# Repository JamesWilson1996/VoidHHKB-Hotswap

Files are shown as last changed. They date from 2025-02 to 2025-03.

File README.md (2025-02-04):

# VoidHHKB-Hotswap

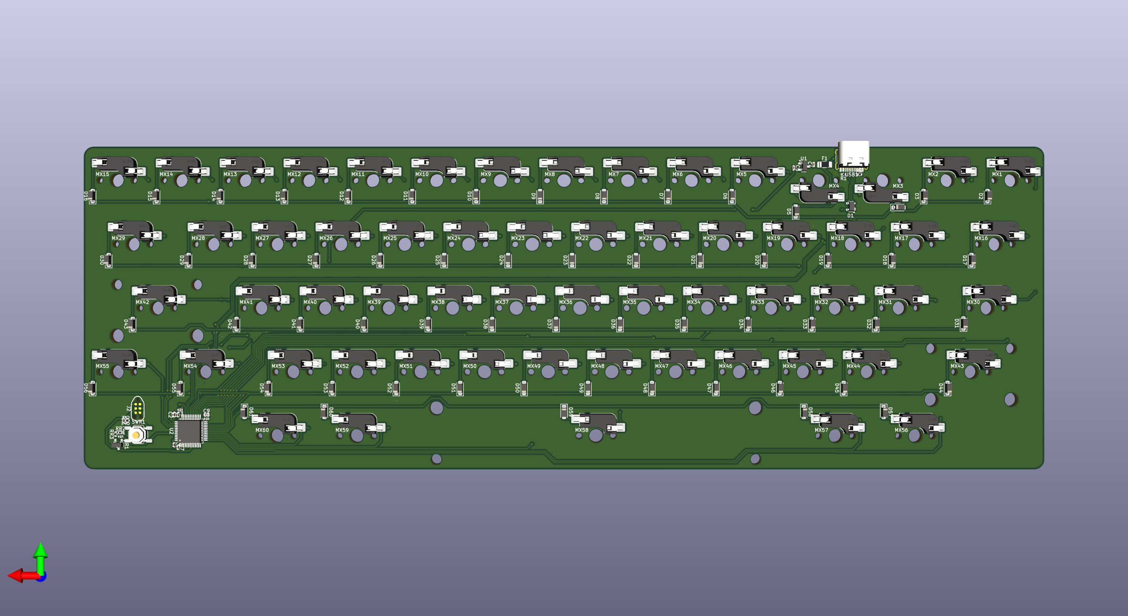
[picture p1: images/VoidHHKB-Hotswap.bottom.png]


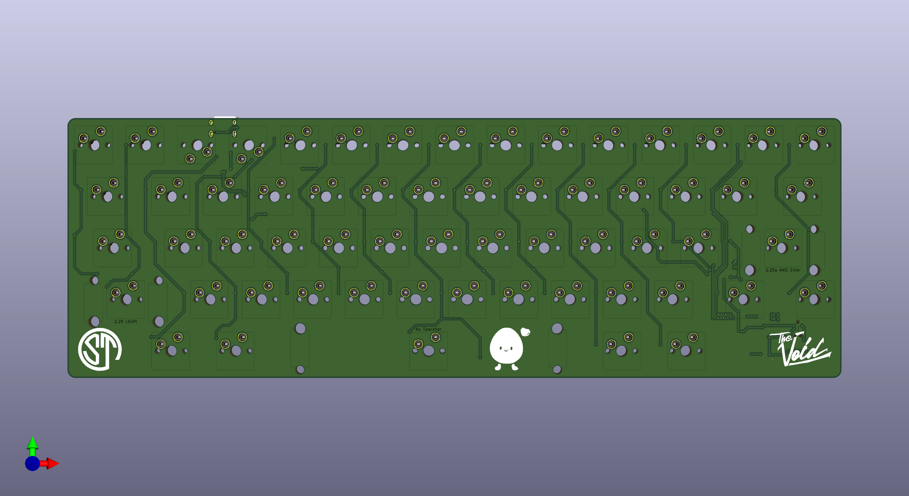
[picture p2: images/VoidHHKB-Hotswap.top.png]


## Ordering from JLCPCB

1) Head to the [JLCPCB order page](https://cart.jlcpcb.com/quote).

2) Upload the `VoidHHKB-Hotswap.zip` file in `production/`.

3) Set the quantity of the PCBs you want made.

4) Set your desired PCB parameters. Here are some suggested parameters: (Everything else can be kept at their default)

- PCB Color: **Purple**
- Surface Finish: **ENIG**
- Remove Order Number: **Yes**   

5) Enable the PCB Assembly option at the bottom, and set the following parameters:

- PCBA Type: **Standard**
- Assembly Side: **Bottom**

6) Press `Confirm` at the bottom or `NEXT` on the right to get to the next page.

7) Click `NEXT` to get to the Bill of Materials tab.

8) Click `Add BOM File` and select the `bom.csv` file in `production/`.

9) Click `Add CPL File` and select the `positions.csv` file in `production/`. Click `Process BOM & CPL` to proceed.

10) You should be presented with a list of all the components and quantities needed. Double check there are no missing components. If there are, you will have to find substitute components for it. Click `NEXT` to proceed.

11) You should be presented with a view of the PCB and its components. You will most likely need to rotate the Hotswap sockets manually. Click `NEXT` to proceed.

12) You should see a breakdown of the price for the PCBs you want to order. Select `Keyboard - HS Code 847330` under `Office Appliance Accessories` for the Product Description.

13) Save to cart, and pay for it!

## Flashing Firmware

1) Install and launch [QMK Toolbox](https://qmk.fm/toolbox)

2) Connect PCB via USB. Hold down reset button to enter bootloader

3) Under 'Local file' open firmware/void_voidhhkb_via.bin. Everything else can be left as default (MCU should be ATmega32U4)

4) Click Flash!

5) Unplug and plug in again to complete set up

## Using VIA

Temp instructions until I get around to merging files into QMK repo...
1) To edit keymap in via open web page and select 'Design' on the top ribbon

2) Click 'Load Draft Definition' and load '/firmware/voidhhkb/via.json'

## Build your own firmware

- Files have been included under 'firmware' if you want to build the bin files yourself.
- This is fairly trivial to do by following the [QMK Tutorial](https://docs.qmk.fm/newbs)

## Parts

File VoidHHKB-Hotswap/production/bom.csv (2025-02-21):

Designator | Footprint | Quantity | Value | LCSC Part #
C1, C8 | 0402 | 2 | 4.7uF | C23733
C2, C3, C7, C9 | 0402 | 4 | 100nF | C1525
C4, C5, C6, CR2 | 0402 | 4 | 1uF | C52923
CR1 | 0402 | 1 | 10uF | C15525
D1 | SOT-143 | 1 | PRTR5V0U2X | C2827688
D10, D11, D12, D13, D14, D15, D16, D17, D18, D19, D2, D20, D21, D22, D23, D24, D25, D26, D27, D28, D29, D3, D30, D31, D32, D33, D34, D35, D36, D37, D38, D39, D4, D40, D41, D42, D43, D44, D45, D46, D47, D48, D49, D5, D50, D51, D52, D53, D54, D55, D56, D57, D58, D59, D6, D60, D61, D7, D8, D9 | D_SOD-123 | 60 | 1N4148W
F1 | 1206 | 1 | 500mA | C69688
MX1, MX10, MX11, MX12, MX13, MX14, MX15, MX17, MX18, MX19, MX2, MX20, MX21, MX22, MX23, MX24, MX25, MX26, MX27, MX28, MX3, MX31, MX32, MX33, MX34, MX35, MX36, MX37, MX38, MX39, MX4, MX40, MX41, MX42, MX43, MX44, MX45, MX46, MX47, MX48, MX49, MX5, MX50, MX51, MX52, MX53, MX55, MX56, MX58, MX6, MX60, MX7, MX8, MX9 | SW_MX_HS_CPG151101S11_1u | 54 | MX_SW_HS
MX16, MX29, MX57, MX59 | SW_MX_HS_CPG151101S11_1.5u | 4 | MX_SW_HS
MX30, MX54 | SW_MX_HS_CPG151101S11_1.75u | 2 | MX_SW_HS
QR1 | SOT-23 | 1 | 2N7002 | C8545
R1, R2 | 0402 | 2 | 5k1 | C25905
RR1 | 0402 | 1 | 33k | C25779
RR2 | 0402 | 1 | 10k | C25744
RR3 | 0402 | 1 | 100k | C25741
SWR1 | SW_SPST_TL3342 | 1 | TS-1187A-B-A-B | C318884
U1 | SOT-23 | 1 | XC6206P332MR | C5446
U2 | LQFP-48_7x7mm_P0.5mm | 1 | STM32F072CBT6 | C81720
USB1 | USB_C_Receptacle_HRO_TYPE-C-31-M-12 | 1 | USB_C_Receptacle_USB2.0_16P | C165948

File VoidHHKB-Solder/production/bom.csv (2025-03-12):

Designator | Footprint | Quantity | Value | LCSC Part #
C1, C8 | 0402 | 2 | 4.7uF | C23733
C2, C3, C7, C9 | 0402 | 4 | 100nF | C1525
C4, C5, C6, CR2 | 0402 | 4 | 1uF | C52923
CR1 | 0402 | 1 | 10uF | C15525
D1 | SOT-143 | 1 | PRTR5V0U2X | C2827688
D10, D11, D12, D13, D14, D15, D16, D17, D18, D19, D2, D20, D21, D22, D23, D24, D25, D26, D27, D28, D29, D3, D30, D31, D32, D33, D34, D35, D36, D37, D38, D39, D4, D40, D41, D42, D43, D44, D45, D46, D47, D48, D49, D5, D50, D51, D52, D53, D54, D55, D56, D57, D58, D59, D6, D60, D61, D62, D63, D7, D8, D9 | D_SOD-123 | 62 | 1N4148W
F1 | 1206 | 1 | 500mA | C69688
MX1 | SW_MX_1u | 1 | Esc
MX10 | SW_MX_1u | 1 | 9
MX11 | SW_MX_1u | 1 | 10
MX12 | SW_MX_1u | 1 | -
MX13 | SW_MX_1u | 1 | =
MX14 | SW_MX_1u | 1 | \
MX15 | SW_MX_1u | 1 | `
MX16 | SW_MX_1u | 1 | Full Backspace
MX17 | SW_MX_1.5u | 1 | Tab
MX18 | SW_MX_1u | 1 | Q
MX19 | SW_MX_1u | 1 | W
MX2 | SW_MX_1u | 1 | 1
MX20 | SW_MX_1u | 1 | E
MX21 | SW_MX_1u | 1 | R
MX22 | SW_MX_1u | 1 | T
MX23 | SW_MX_1u | 1 | Y
MX24 | SW_MX_1u | 1 | U
MX25 | SW_MX_1u | 1 | I
MX26 | SW_MX_1u | 1 | O
MX27 | SW_MX_1u | 1 | P
MX28 | SW_MX_1u | 1 | [
MX29 | SW_MX_1u | 1 | ]
MX3 | SW_MX_1u | 1 | 2
MX30 | SW_MX_1.5u | 1 | Backspace
MX31 | SW_MX_1.75u_STP_1.25 | 1 | Stepped Caps
MX32 | SW_MX_1u | 1 | A
MX33 | SW_MX_1u | 1 | S
MX34 | SW_MX_1u | 1 | D
MX35 | SW_MX_1u | 1 | F
MX36 | SW_MX_1u | 1 | G
MX37 | SW_MX_1u | 1 | H
MX38 | SW_MX_1u | 1 | J
MX39 | SW_MX_1u | 1 | K
MX4 | SW_MX_1u | 1 | 3
MX40 | SW_MX_1u | 1 | L
MX41 | SW_MX_1u | 1 | ;
MX42 | SW_MX_1u | 1 | '
MX43, MX48 | SW_MX_1u | 2 | NUHS
MX44 | SW_MX_1u | 1 | ANSI Enter
MX45 | SW_MX_1.75u | 1 | Caps
MX46 | SW_MX_1u | 1 | ISO Enter
MX47 | SW_MX_1u | 1 | LShift
MX49 | SW_MX_1u | 1 | Z
MX5 | SW_MX_1u | 1 | 4
MX50 | SW_MX_1u | 1 | X
MX51 | SW_MX_1u | 1 | C
MX52 | SW_MX_1u | 1 | V
MX53 | SW_MX_1u | 1 | B
MX54 | SW_MX_1u | 1 | N
MX55 | SW_MX_1u | 1 | M
MX56 | SW_MX_1u | 1 | ,
MX57 | SW_MX_1u | 1 | .
MX58 | SW_MX_1u | 1 | /
MX59 | SW_MX_1.75u | 1 | RShift 1.75u
MX6 | SW_MX_1u | 1 | 5
MX60 | SW_MX_1u | 1 | fn
MX61 | SW_MX_1.25u | 1 | LShift 1.25u
MX62 | SW_MX_1u | 1 | RShift 2.75u
MX63, MX67 | SW_MX_1u | 2 | Alt
MX64, MX66 | SW_MX_1.5u | 2 | Super
MX65 | SW_MX_1u | 1 | Spacebar
MX68 | SW_MX_1u | 1 | Off Center Spacebar
MX7 | SW_MX_1u | 1 | 6
MX8 | SW_MX_1u | 1 | 7
MX9 | SW_MX_1u | 1 | 8
QR1 | SOT-23 | 1 | 2N7002 | C8545
R1, R2 | 0402 | 2 | 5k1 | C25905
RR1 | 0402 | 1 | 33k | C25779
RR2 | 0402 | 1 | 10k | C25744
RR3 | 0402 | 1 | 100k | C25741
S1 | STAB_MX_2u | 1 | 2u Backspace
S3 | STAB_MX_ISO-ROT | 1 | ISO Enter
SWR1 | SW_SPST_TL3342 | 1 | TS-1187A-B-A-B | C318884
U1 | SOT-23 | 1 | XC6206P332MR | C5446
U2 | LQFP-48_7x7mm_P0.5mm | 1 | STM32F072CBT6 | C81720
USB1 | USB_C_Receptacle_HRO_TYPE-C-31-M-12 | 1 | USB_C_Receptacle_USB2.0_16P | C165948

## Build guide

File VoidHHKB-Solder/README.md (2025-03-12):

# VoidHHKB-Solder

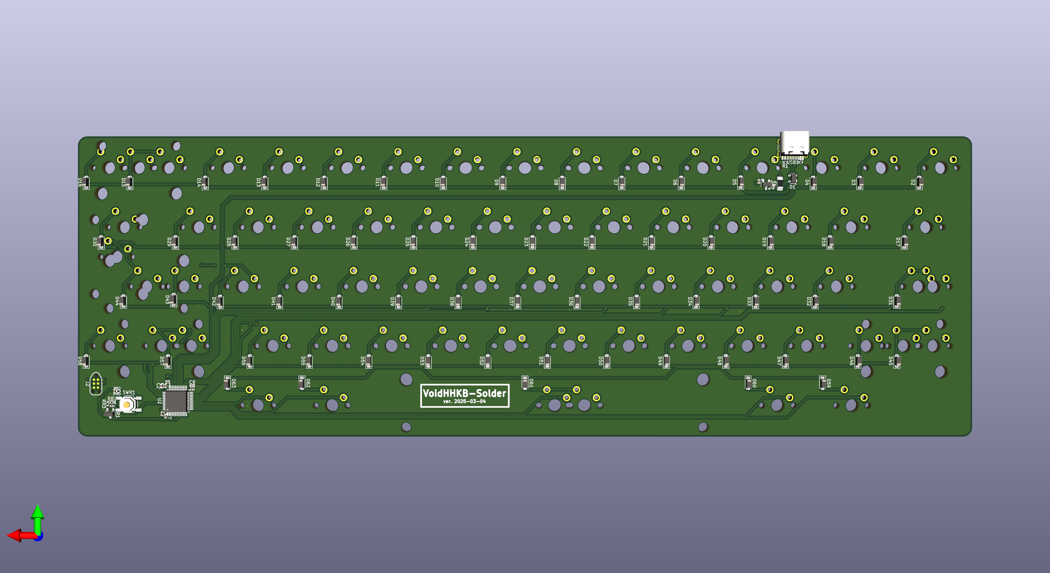
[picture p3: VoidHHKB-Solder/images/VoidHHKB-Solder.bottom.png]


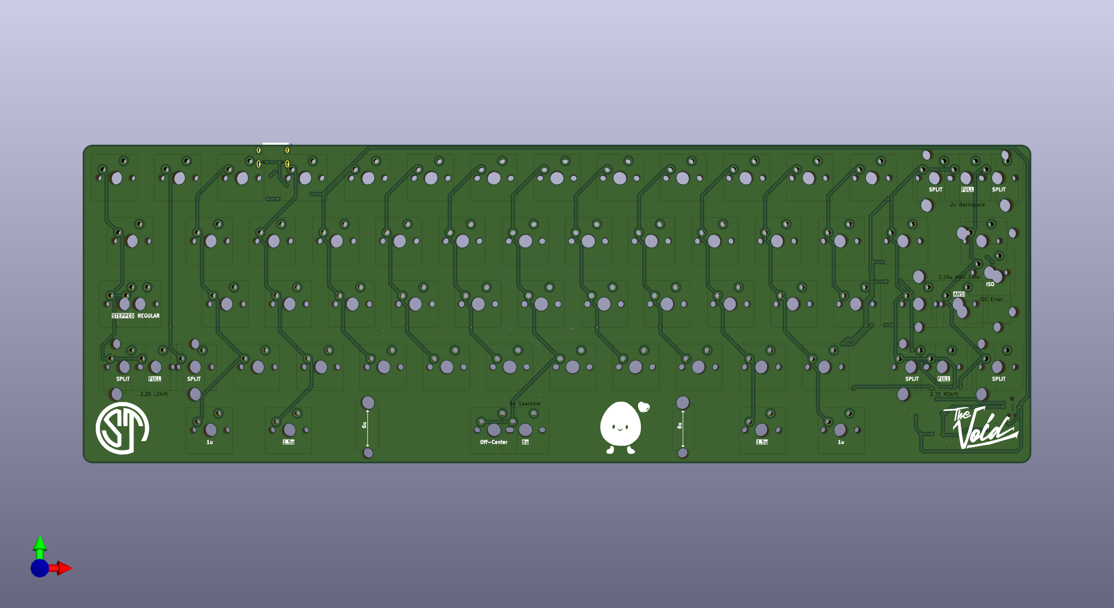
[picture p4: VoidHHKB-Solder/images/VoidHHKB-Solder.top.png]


## Ordering from JLCPCB

1) Head to the [JLCPCB order page](https://cart.jlcpcb.com/quote).

2) Upload the `VoidHHKB-Solder.zip` file in `production/`.

3) Set the quantity of the PCBs you want made.

4) Set your desired PCB parameters. Here are some suggested parameters: (Everything else can be kept at their default)

- PCB Color: **Purple**
- Surface Finish: **ENIG**
- Remove Order Number: **Yes**   

5) Enable the PCB Assembly option at the bottom, and set the following parameters:

- PCBA Type: **Standard**
- Assembly Side: **Bottom**

6) Press `Confirm` at the bottom or `NEXT` on the right to get to the next page.

7) Click `NEXT` to get to the Bill of Materials tab.

8) Click `Add BOM File` and select the `bom.csv` file in `production/`.

9) Click `Add CPL File` and select the `positions.csv` file in `production/`. Click `Process BOM & CPL` to proceed.

10) You should be presented with a list of all the components and quantities needed. Double check there are no missing components. If there are, you will have to find substitute components for it. Click `NEXT` to proceed.

11) You should be presented with a view of the PCB and its components. Click `NEXT` to proceed.

12) You should see a breakdown of the price for the PCBs you want to order. Select `Keyboard - HS Code 847330` under `Office Appliance Accessories` for the Product Description.

13) Save to cart, and pay for it!

## Flashing Firmware

1) Install and launch [QMK Toolbox](https://qmk.fm/toolbox)

2) Connect PCB via USB. Hold down reset button to enter bootloader

3) Under 'Local file' open firmware/void_voidhhkb_via.bin. Everything else can be left as default (MCU should be ATmega32U4)

4) Click Flash!

5) Unplug and plug in again to complete set up

## Using VIA

Temp instructions until I get around to merging files into QMK repo...
1) To edit keymap in via open web page and select 'Design' on the top ribbon

2) Click 'Load Draft Definition' and load '/firmware/voidhhkb/via.json'

## Build your own firmware

- Files have been included under 'firmware' if you want to build the bin files yourself.
- This is fairly trivial to do by following the [QMK Tutorial](https://docs.qmk.fm/newbs)

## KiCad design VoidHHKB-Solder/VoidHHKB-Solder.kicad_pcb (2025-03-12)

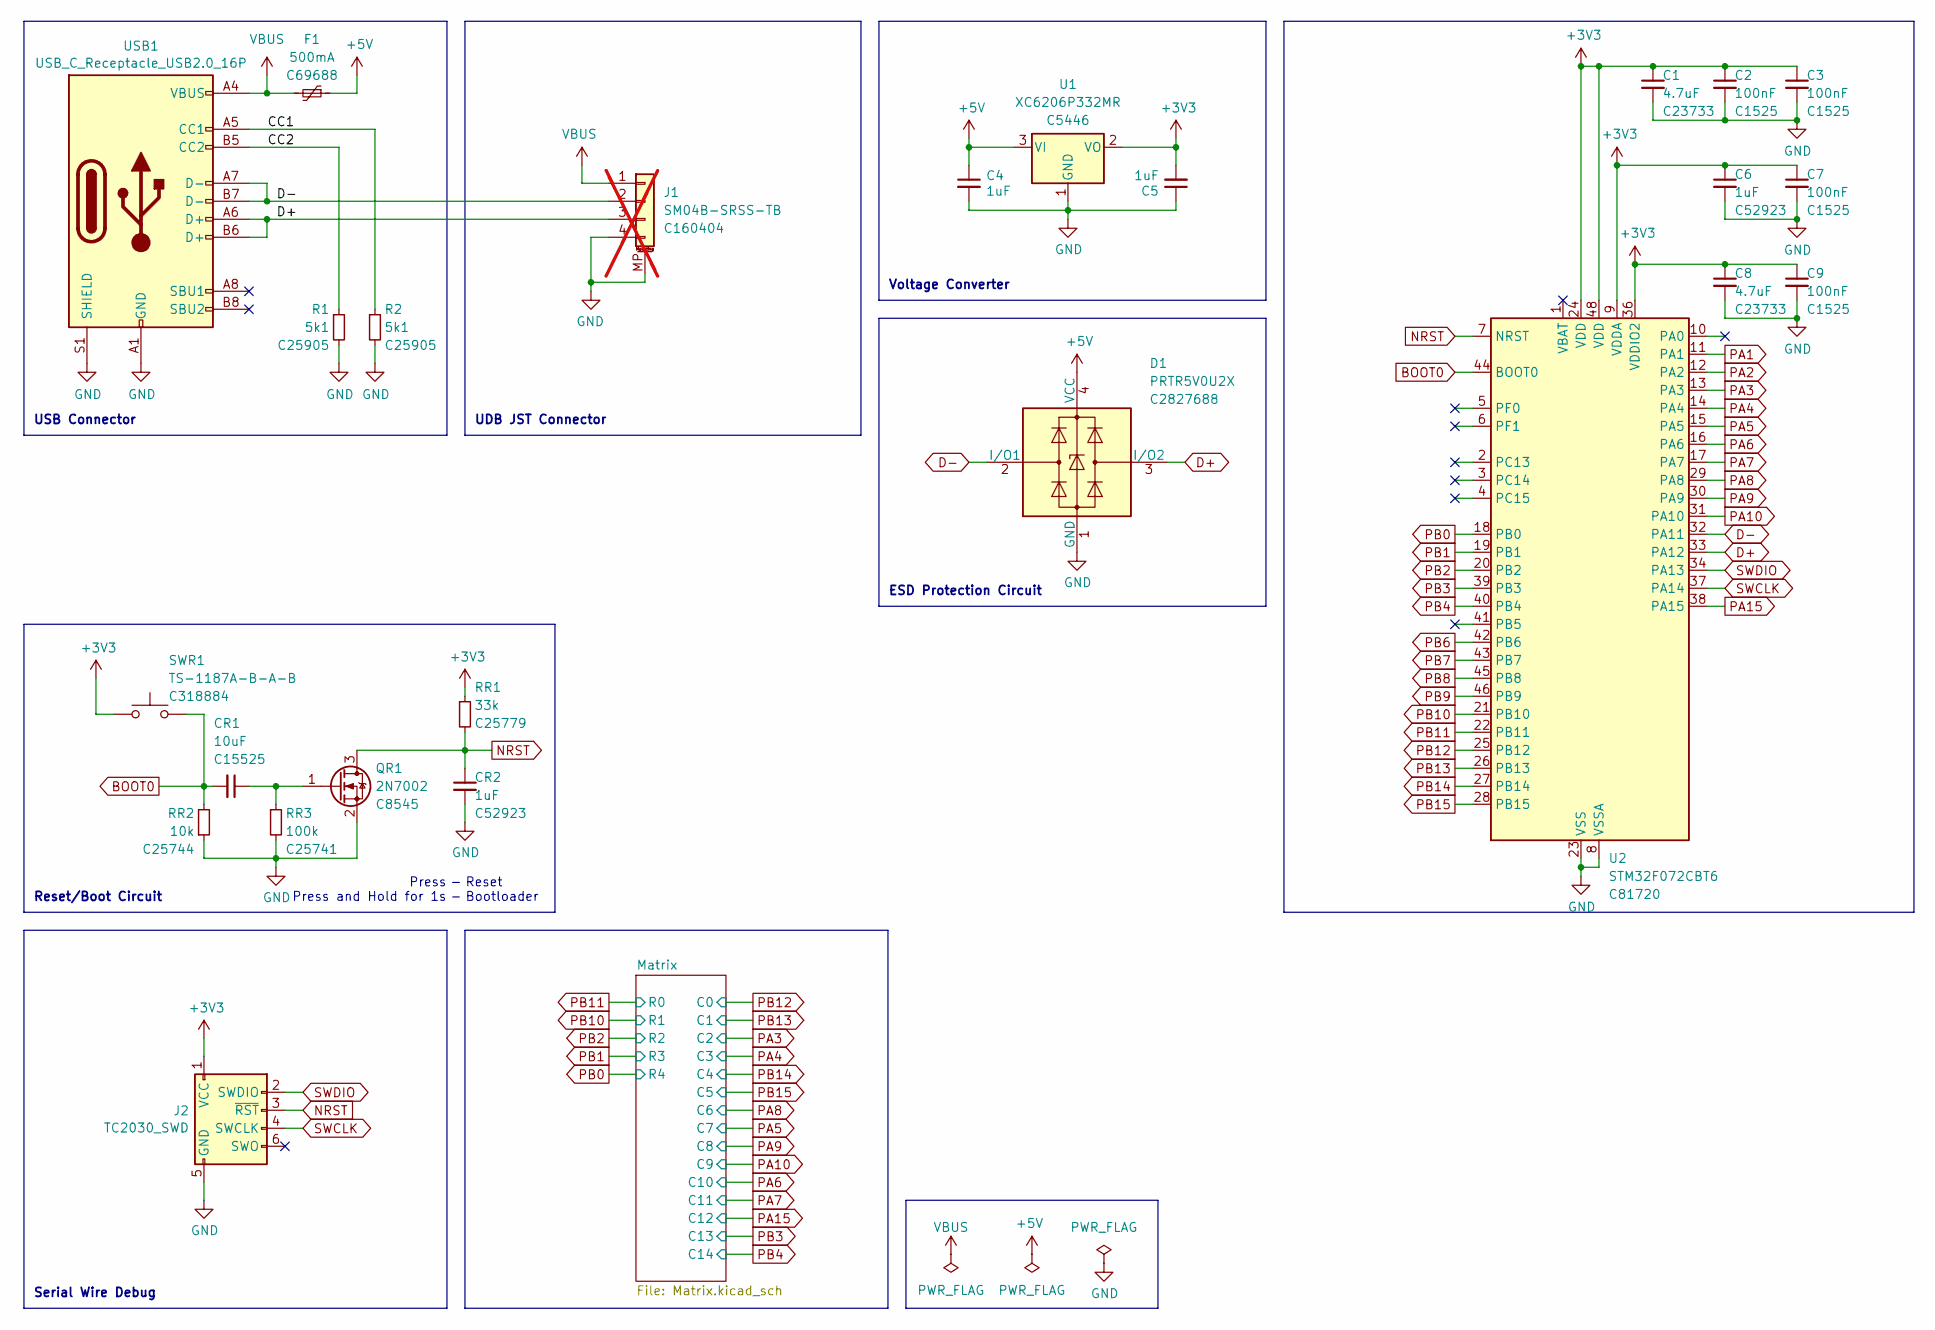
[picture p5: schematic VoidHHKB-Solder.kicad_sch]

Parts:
C1, C8: 4.7uF; C_0402_1005Metric; MPN CL05A475MP5NRNC; LCSC C23733
C2, C3, C7, C9: 100nF; C_0402_1005Metric; MPN CL05B104KO5NNNC; LCSC C1525
C4, C5, C6: 1uF; C_0402_1005Metric; MPN CL05A105KA5NQNC; LCSC C52923
CR1: 10uF; C_0402_1005Metric; MPN CL05A106MQ5NUNC; LCSC C15525
CR2: 1uF; C_0402_1005Metric; MPN CL05A105KA5NQNC; LCSC C52923
D1: PRTR5V0U2X; SOT-143; MPN PRTR5V0U2X; LCSC C2827688
F1: 500mA; Fuse_1206_3216Metric_Pad1.42x1.75mm_HandSolder; MPN nSMD050; LCSC C69688
J1: SM04B-SRSS-TB; JST_SH_SM04B-SRSS-TB_1x04-1MP_P1.00mm_Horizontal; MPN SM04B-SRSS-TB(LF)(SN); LCSC C160404; not fitted
J2: TC2030_SWD; CON_TC2030_outlined
QR1: 2N7002; SOT-23; MPN 2N7002; LCSC C8545
R1, R2: 5k1; R_0402_1005Metric; MPN 0402WGF5101TCE; LCSC C25905
RR1: 33k; R_0402_1005Metric; MPN 0402WGF3302TCE; LCSC C25779
RR2: 10k; R_0402_1005Metric; MPN 0402WGF1002TCE; LCSC C25744
RR3: 100k; R_0402_1005Metric; MPN 0402WGF1003TCE; LCSC C25741
SWR1: TS-1187A-B-A-B; SW_SPST_TL3342; MPN TS-1187A-B-A-B; LCSC C318884
U1: XC6206P332MR; SOT-23; MPN XC6206P332MR-G; LCSC C5446
U2: STM32F072CBT6; LQFP-48_7x7mm_P0.5mm; MPN STM32F072CBT6; LCSC C81720
USB1: USB_C_Receptacle_USB2.0_16P; USB_C_Receptacle_HRO_TYPE-C-31-M-12; MPN TYPE-C-31-M-12; LCSC C165948

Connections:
+3V3: C1.1, C2.1, C3.1, C5.2, C6.1, C7.1, C8.1, C9.1, J2.1 (VCC), RR1.1, SWR1.1, U1.2 (VO), U2.9 (VDDA), U2.24 (VDD), U2.36 (VDDIO2), U2.48 (VDD)
+5V: C4.1, D1.4 (VCC), F1.1, U1.3 (VI)
/CC1: R2.1, USB1.A5 (CC1)
/CC2: R1.1, USB1.B5 (CC2)
BOOT0: CR1.2, RR2.2, SWR1.2, U2.44 (BOOT0)
D+: D1.3 (I/O2), J1.3, U2.33 (PA12), USB1.A6 (D+), USB1.B6 (D+)
D-: D1.2 (I/O1), J1.2, U2.32 (PA11), USB1.A7 (D-), USB1.B7 (D-)
GND: C1.2, C2.2, C3.2, C4.2, C5.1, C6.2, C7.2, C8.2, C9.2, CR2.2, D1.1 (GND), J1.4, J1.MP (MountPin), J2.5 (GND), QR1.2 (S), R1.2, R2.2, RR2.1, RR3.2, U1.1 (GND), U2.8 (VSSA), U2.23 (VSS), U2.35 (VSS), U2.47 (VSS), USB1.A1 (GND), USB1.A12 (GND), USB1.B1 (GND), USB1.B12 (GND), USB1.S1 (SHIELD)
NRST: CR2.1, J2.3 (~RST), QR1.3 (D), RR1.2, U2.7 (NRST)
unnamed: CR1.1, QR1.1 (G), RR3.1
PA1: U2.11 (PA1)
PA2: U2.12 (PA2)
PA3: U2.13 (PA3); also elsewhere on the board
PA4: U2.14 (PA4); also elsewhere on the board
PA5: U2.15 (PA5); also elsewhere on the board
PA6: U2.16 (PA6); also elsewhere on the board
PA7: U2.17 (PA7); also elsewhere on the board
PA8: U2.29 (PA8); also elsewhere on the board
PA9: U2.30 (PA9); also elsewhere on the board
PA10: U2.31 (PA10); also elsewhere on the board
PA15: U2.38 (PA15); also elsewhere on the board
PB0: U2.18 (PB0); also elsewhere on the board
PB1: U2.19 (PB1); also elsewhere on the board
PB2: U2.20 (PB2); also elsewhere on the board
PB3: U2.39 (PB3); also elsewhere on the board
PB4: U2.40 (PB4); also elsewhere on the board
PB6: U2.42 (PB6)
PB7: U2.43 (PB7)
PB8: U2.45 (PB8)
PB9: U2.46 (PB9)
PB10: U2.21 (PB10); also elsewhere on the board
PB11: U2.22 (PB11); also elsewhere on the board
PB12: U2.25 (PB12); also elsewhere on the board
PB13: U2.26 (PB13); also elsewhere on the board
PB14: U2.27 (PB14); also elsewhere on the board
PB15: U2.28 (PB15); also elsewhere on the board
SWCLK: J2.4 (SWCLK), U2.37 (PA14)
SWDIO: J2.2 (SWDIO), U2.34 (PA13)
VBUS: F1.2, J1.1, USB1.A4 (VBUS), USB1.A9 (VBUS), USB1.B4 (VBUS), USB1.B9 (VBUS)

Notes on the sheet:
Reset Bootloader
- -
ESD Protection Circuit
Voltage Converter
Serial Wire Debug
Press Press and Hold for 1s
Reset/Boot Circuit
USB Connector
UDB JST Connector

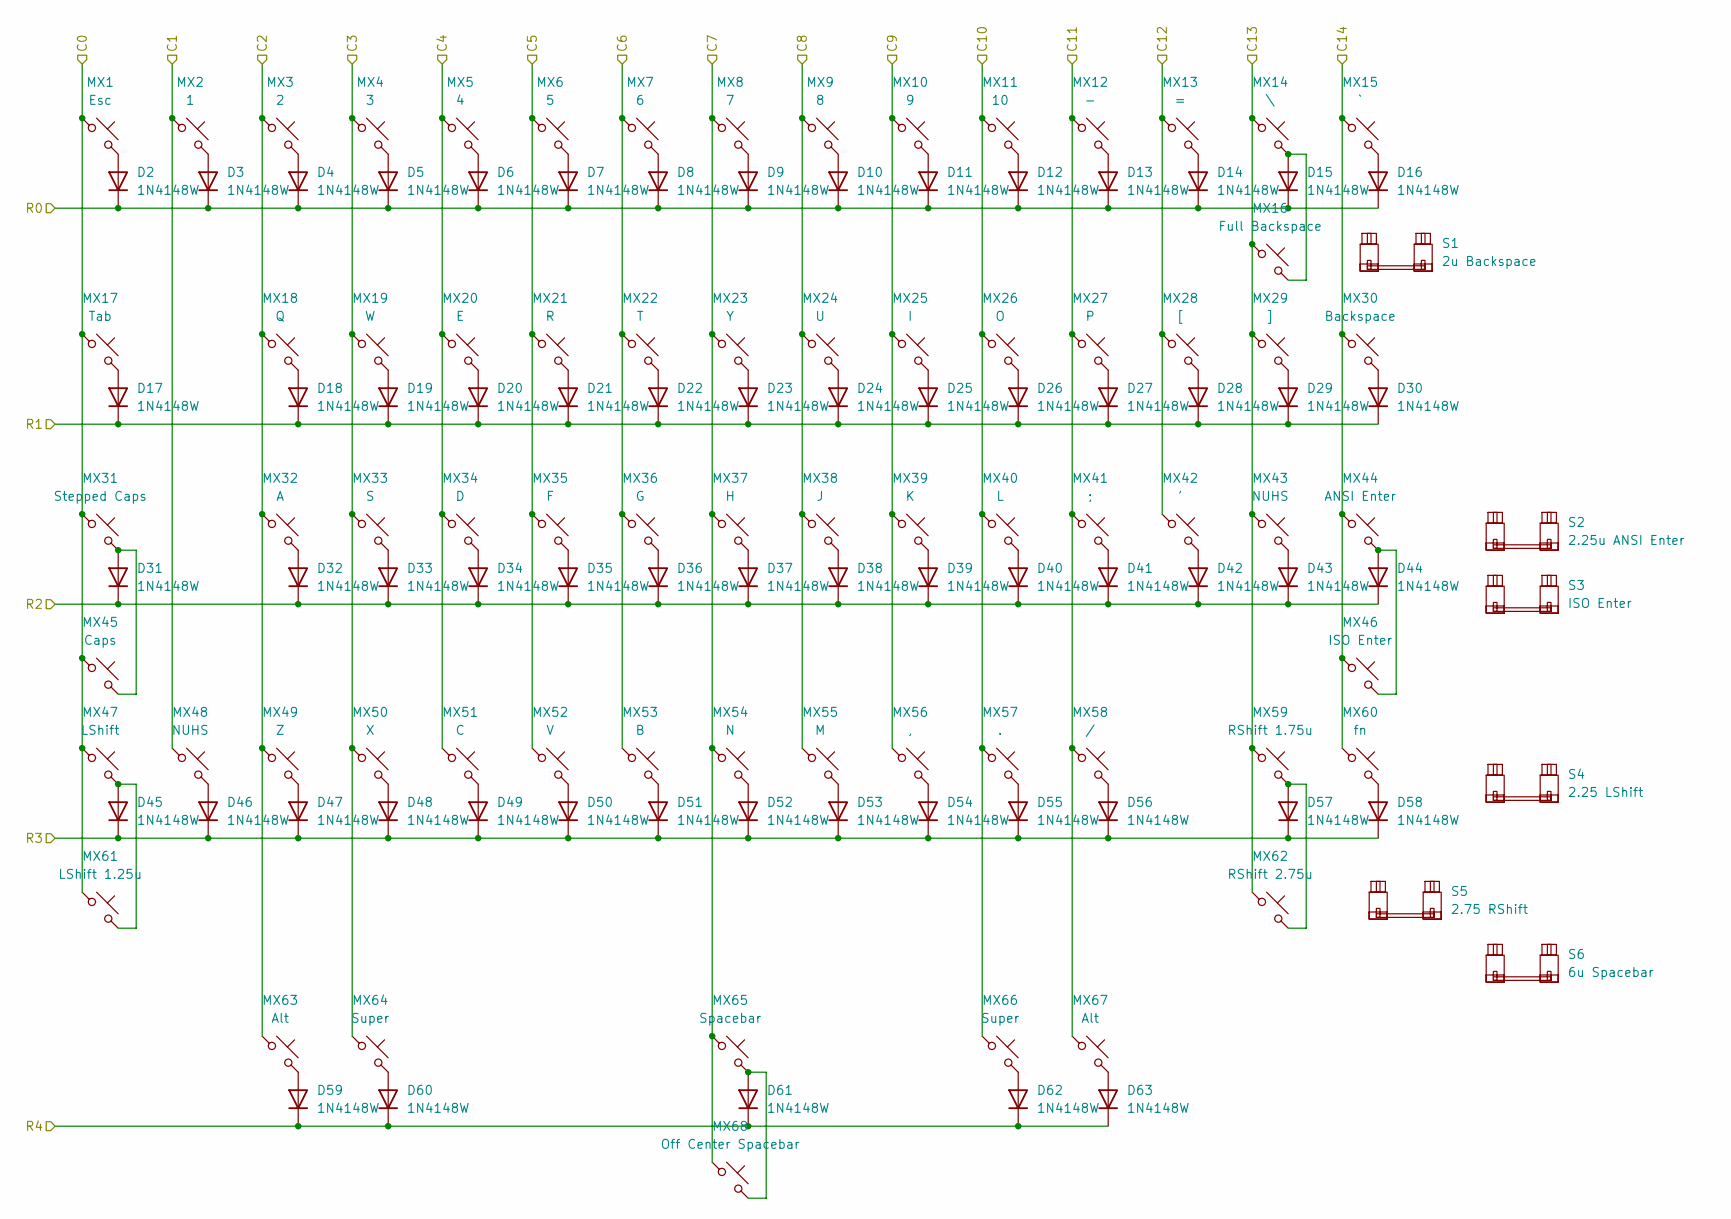
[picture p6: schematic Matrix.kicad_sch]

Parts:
D2, D3, D4, D5, D6, D7, D8, D9, D10, D11, D12, D13, D14, D15, D16, D17, D18, D19, D20, D21, D22, D23, D24, D25, D26, D27, D28, D29, D30, D31, D32, D33, D34, D35, D36, D37, D38, D39, D40, D41, D42, D43, D44, D45, D46, D47, D48, D49, D50, D51, D52, D53, D54, D55, D56, D57, D58, D59, D60, D61, D62, D63: 1N4148W; D_SOD-123
MX1: Esc; SW_MX_1u
MX2: 1; SW_MX_1u
MX3: 2; SW_MX_1u
MX4: 3; SW_MX_1u
MX5: 4; SW_MX_1u
MX6: 5; SW_MX_1u
MX7: 6; SW_MX_1u
MX8: 7; SW_MX_1u
MX9: 8; SW_MX_1u
MX10: 9; SW_MX_1u
MX11: 10; SW_MX_1u
MX12: -; SW_MX_1u
MX13: =; SW_MX_1u
MX14: \; SW_MX_1u
MX15: `; SW_MX_1u
MX16: Full Backspace; SW_MX_1u
MX17: Tab; SW_MX_1.5u
MX18: Q; SW_MX_1u
MX19: W; SW_MX_1u
MX20: E; SW_MX_1u
MX21: R; SW_MX_1u
MX22: T; SW_MX_1u
MX23: Y; SW_MX_1u
MX24: U; SW_MX_1u
MX25: I; SW_MX_1u
MX26: O; SW_MX_1u
MX27: P; SW_MX_1u
MX28: [; SW_MX_1u
MX29: ]; SW_MX_1u
MX30: Backspace; SW_MX_1.5u
MX31: Stepped Caps; SW_MX_1.75u_STP_1.25
MX32: A; SW_MX_1u
MX33: S; SW_MX_1u
MX34: D; SW_MX_1u
MX35: F; SW_MX_1u
MX36: G; SW_MX_1u
MX37: H; SW_MX_1u
MX38: J; SW_MX_1u
MX39: K; SW_MX_1u
MX40: L; SW_MX_1u
MX41: ;; SW_MX_1u
MX42: '; SW_MX_1u
MX43, MX48: NUHS; SW_MX_1u
MX44: ANSI Enter; SW_MX_1u
MX45: Caps; SW_MX_1.75u
MX46: ISO Enter; SW_MX_1u
MX47: LShift; SW_MX_1u
MX49: Z; SW_MX_1u
MX50: X; SW_MX_1u
MX51: C; SW_MX_1u
MX52: V; SW_MX_1u
MX53: B; SW_MX_1u
MX54: N; SW_MX_1u
MX55: M; SW_MX_1u
MX56: ,; SW_MX_1u
MX57: .; SW_MX_1u
MX58: /; SW_MX_1u
MX59: RShift 1.75u; SW_MX_1.75u
MX60: fn; SW_MX_1u
MX61: LShift 1.25u; SW_MX_1.25u
MX62: RShift 2.75u; SW_MX_1u
MX63, MX67: Alt; SW_MX_1u
MX64, MX66: Super; SW_MX_1.5u
MX65: Spacebar; SW_MX_1u
MX68: Off Center Spacebar; SW_MX_1u
S1: 2u Backspace; STAB_MX_2u
S2: 2.25u ANSI Enter; STAB_MX_2.25u
S3: ISO Enter; STAB_MX_ISO-ROT
S4: 2.25 LShift; STAB_MX_2.25u
S5: 2.75 RShift; STAB_MX_2.75u
S6: 6u Spacebar; STAB_MX_6u_New

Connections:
unnamed: D2.2 (A), MX1.2
unnamed: D3.2 (A), MX2.2
unnamed: D4.2 (A), MX3.2
unnamed: D5.2 (A), MX4.2
unnamed: D6.2 (A), MX5.2
unnamed: D7.2 (A), MX6.2
unnamed: D8.2 (A), MX7.2
unnamed: D9.2 (A), MX8.2
unnamed: D10.2 (A), MX9.2
unnamed: D11.2 (A), MX10.2
unnamed: D12.2 (A), MX11.2
unnamed: D13.2 (A), MX12.2
unnamed: D14.2 (A), MX13.2
unnamed: D15.2 (A), MX14.2, MX16.2
unnamed: D16.2 (A), MX15.2
unnamed: D17.2 (A), MX17.2
unnamed: D18.2 (A), MX18.2
unnamed: D19.2 (A), MX19.2
unnamed: D20.2 (A), MX20.2
unnamed: D21.2 (A), MX21.2
unnamed: D22.2 (A), MX22.2
unnamed: D23.2 (A), MX23.2
unnamed: D24.2 (A), MX24.2
unnamed: D25.2 (A), MX25.2
unnamed: D26.2 (A), MX26.2
unnamed: D27.2 (A), MX27.2
unnamed: D28.2 (A), MX28.2
unnamed: D29.2 (A), MX29.2
unnamed: D30.2 (A), MX30.2
unnamed: D31.2 (A), MX31.2, MX45.2
unnamed: D32.2 (A), MX32.2
unnamed: D33.2 (A), MX33.2
unnamed: D34.2 (A), MX34.2
unnamed: D35.2 (A), MX35.2
unnamed: D36.2 (A), MX36.2
unnamed: D37.2 (A), MX37.2
unnamed: D38.2 (A), MX38.2
unnamed: D39.2 (A), MX39.2
unnamed: D40.2 (A), MX40.2
unnamed: D41.2 (A), MX41.2
unnamed: D42.2 (A), MX42.2
unnamed: D43.2 (A), MX43.2
unnamed: D44.2 (A), MX44.2, MX46.2
unnamed: D45.2 (A), MX47.2, MX61.2
unnamed: D46.2 (A), MX48.2
unnamed: D47.2 (A), MX49.2
unnamed: D48.2 (A), MX50.2
unnamed: D49.2 (A), MX51.2
unnamed: D50.2 (A), MX52.2
unnamed: D51.2 (A), MX53.2
unnamed: D52.2 (A), MX54.2
unnamed: D53.2 (A), MX55.2
unnamed: D54.2 (A), MX56.2
unnamed: D55.2 (A), MX57.2
unnamed: D56.2 (A), MX58.2
unnamed: D57.2 (A), MX59.2, MX62.2
unnamed: D58.2 (A), MX60.2
unnamed: D59.2 (A), MX63.2
unnamed: D60.2 (A), MX64.2
unnamed: D61.2 (A), MX65.2, MX68.2
unnamed: D62.2 (A), MX66.2
unnamed: D63.2 (A), MX67.2
PA3: MX3.1, MX18.1, MX32.1, MX49.1, MX63.1; also elsewhere on the board
PA4: MX4.1, MX19.1, MX33.1, MX50.1, MX64.1; also elsewhere on the board
PA5: MX8.1, MX23.1, MX37.1, MX54.1, MX65.1, MX68.1; also elsewhere on the board
PA6: MX11.1, MX26.1, MX40.1, MX57.1, MX66.1; also elsewhere on the board
PA7: MX12.1, MX27.1, MX41.1, MX58.1, MX67.1; also elsewhere on the board
PA8: MX7.1, MX22.1, MX36.1, MX53.1; also elsewhere on the board
PA9: MX9.1, MX24.1, MX38.1, MX55.1; also elsewhere on the board
PA10: MX10.1, MX25.1, MX39.1, MX56.1; also elsewhere on the board
PA15: MX13.1, MX28.1, MX42.1; also elsewhere on the board
PB0: D59.1 (K), D60.1 (K), D61.1 (K), D62.1 (K), D63.1 (K); also elsewhere on the board
PB1: D45.1 (K), D46.1 (K), D47.1 (K), D48.1 (K), D49.1 (K), D50.1 (K), D51.1 (K), D52.1 (K), D53.1 (K), D54.1 (K), D55.1 (K), D56.1 (K), D57.1 (K), D58.1 (K); also elsewhere on the board
PB2: D31.1 (K), D32.1 (K), D33.1 (K), D34.1 (K), D35.1 (K), D36.1 (K), D37.1 (K), D38.1 (K), D39.1 (K), D40.1 (K), D41.1 (K), D42.1 (K), D43.1 (K), D44.1 (K); also elsewhere on the board
PB3: MX14.1, MX16.1, MX29.1, MX43.1, MX59.1, MX62.1; also elsewhere on the board
PB4: MX15.1, MX30.1, MX44.1, MX46.1, MX60.1; also elsewhere on the board
PB10: D17.1 (K), D18.1 (K), D19.1 (K), D20.1 (K), D21.1 (K), D22.1 (K), D23.1 (K), D24.1 (K), D25.1 (K), D26.1 (K), D27.1 (K), D28.1 (K), D29.1 (K), D30.1 (K); also elsewhere on the board
PB11: D2.1 (K), D3.1 (K), D4.1 (K), D5.1 (K), D6.1 (K), D7.1 (K), D8.1 (K), D9.1 (K), D10.1 (K), D11.1 (K), D12.1 (K), D13.1 (K), D14.1 (K), D15.1 (K), D16.1 (K); also elsewhere on the board
PB12: MX1.1, MX17.1, MX31.1, MX45.1, MX47.1, MX61.1; also elsewhere on the board
PB13: MX2.1, MX48.1; also elsewhere on the board
PB14: MX5.1, MX20.1, MX34.1, MX51.1; also elsewhere on the board
PB15: MX6.1, MX21.1, MX35.1, MX52.1; also elsewhere on the board

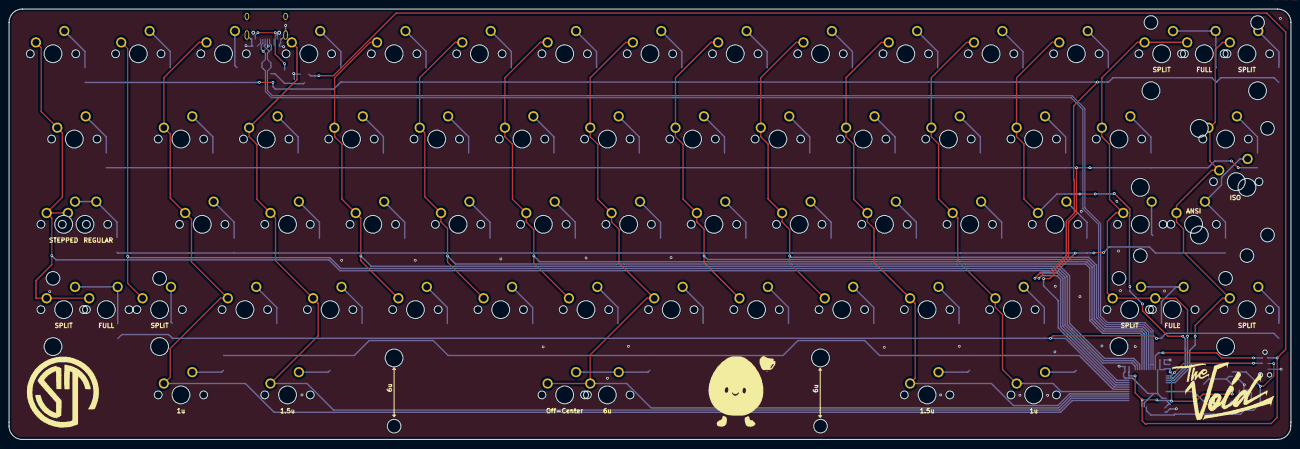
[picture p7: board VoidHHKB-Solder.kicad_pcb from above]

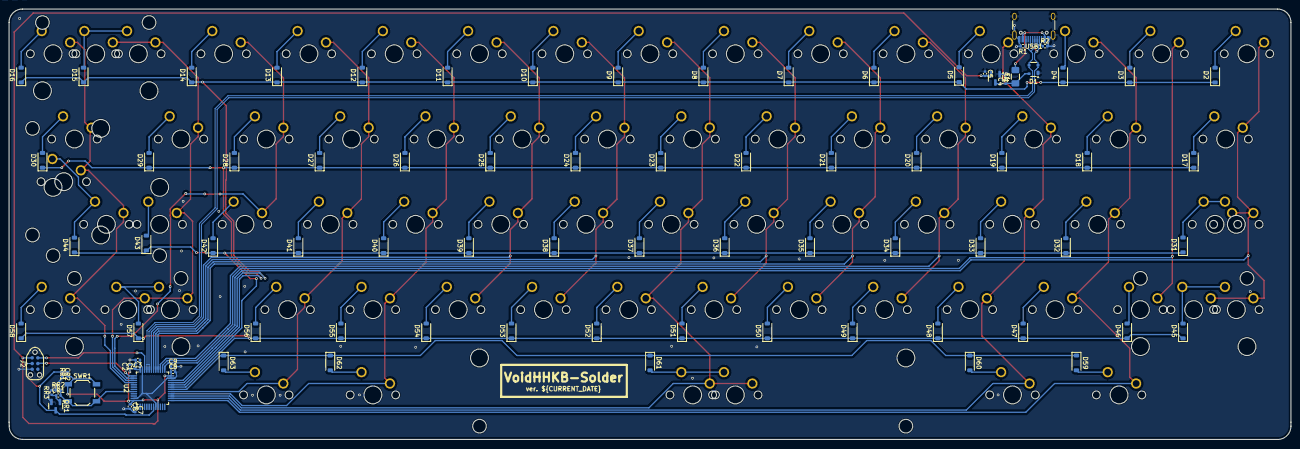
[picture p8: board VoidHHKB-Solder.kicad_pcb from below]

Board: 2 copper layers, 286.4 x 96.1 mm, 160 parts (86 on the bottom side), 95 nets.

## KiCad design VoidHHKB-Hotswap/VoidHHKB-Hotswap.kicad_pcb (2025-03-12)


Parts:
C1, C8: 4.7uF; C_0402_1005Metric; MPN CL05A475MP5NRNC; LCSC C23733
C2, C3, C7, C9: 100nF; C_0402_1005Metric; MPN CL05B104KO5NNNC; LCSC C1525
C4, C5, C6: 1uF; C_0402_1005Metric; MPN CL05A105KA5NQNC; LCSC C52923
CR1: 10uF; C_0402_1005Metric; MPN CL05A106MQ5NUNC; LCSC C15525
CR2: 1uF; C_0402_1005Metric; MPN CL05A105KA5NQNC; LCSC C52923
D1: PRTR5V0U2X; SOT-143; MPN PRTR5V0U2X; LCSC C2827688
F1: 500mA; Fuse_1206_3216Metric_Pad1.42x1.75mm_HandSolder; MPN nSMD050; LCSC C69688
J1: SM04B-SRSS-TB; JST_SH_SM04B-SRSS-TB_1x04-1MP_P1.00mm_Horizontal; MPN SM04B-SRSS-TB(LF)(SN); LCSC C160404; not fitted
J2: TC2030_SWD; CON_TC2030_outlined
QR1: 2N7002; SOT-23; MPN 2N7002; LCSC C8545
R1, R2: 5k1; R_0402_1005Metric; MPN 0402WGF5101TCE; LCSC C25905
RR1: 33k; R_0402_1005Metric; MPN 0402WGF3302TCE; LCSC C25779
RR2: 10k; R_0402_1005Metric; MPN 0402WGF1002TCE; LCSC C25744
RR3: 100k; R_0402_1005Metric; MPN 0402WGF1003TCE; LCSC C25741
SWR1: TS-1187A-B-A-B; SW_SPST_TL3342; MPN TS-1187A-B-A-B; LCSC C318884
U1: XC6206P332MR; SOT-23; MPN XC6206P332MR-G; LCSC C5446
U2: STM32F072CBT6; LQFP-48_7x7mm_P0.5mm; MPN STM32F072CBT6; LCSC C81720
USB1: USB_C_Receptacle_USB2.0_16P; USB_C_Receptacle_HRO_TYPE-C-31-M-12; MPN TYPE-C-31-M-12; LCSC C165948

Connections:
+3V3: C1.1, C2.1, C3.1, C5.2, C6.1, C7.1, C8.1, C9.1, J2.1 (VCC), RR1.1, SWR1.1, U1.2 (VO), U2.9 (VDDA), U2.24 (VDD), U2.36 (VDDIO2), U2.48 (VDD)
+5V: C4.1, D1.4 (VCC), F1.1, U1.3 (VI)
/CC1: R2.1, USB1.A5 (CC1)
/CC2: R1.1, USB1.B5 (CC2)
BOOT0: CR1.2, RR2.2, SWR1.2, U2.44 (BOOT0)
D+: D1.3 (I/O2), J1.3, U2.33 (PA12), USB1.A6 (D+), USB1.B6 (D+)
D-: D1.2 (I/O1), J1.2, U2.32 (PA11), USB1.A7 (D-), USB1.B7 (D-)
GND: C1.2, C2.2, C3.2, C4.2, C5.1, C6.2, C7.2, C8.2, C9.2, CR2.2, D1.1 (GND), J1.4, J1.MP (MountPin), J2.5 (GND), QR1.2 (S), R1.2, R2.2, RR2.1, RR3.2, U1.1 (GND), U2.8 (VSSA), U2.23 (VSS), U2.35 (VSS), U2.47 (VSS), USB1.A1 (GND), USB1.A12 (GND), USB1.B1 (GND), USB1.B12 (GND), USB1.S1 (SHIELD)
NRST: CR2.1, J2.3 (~RST), QR1.3 (D), RR1.2, U2.7 (NRST)
unnamed: CR1.1, QR1.1 (G), RR3.1
PA1: U2.11 (PA1)
PA2: U2.12 (PA2)
PA3: U2.13 (PA3); also elsewhere on the board
PA4: U2.14 (PA4); also elsewhere on the board
PA5: U2.15 (PA5); also elsewhere on the board
PA6: U2.16 (PA6); also elsewhere on the board
PA7: U2.17 (PA7); also elsewhere on the board
PA8: U2.29 (PA8); also elsewhere on the board
PA9: U2.30 (PA9); also elsewhere on the board
PA10: U2.31 (PA10); also elsewhere on the board
PA15: U2.38 (PA15); also elsewhere on the board
PB0: U2.18 (PB0); also elsewhere on the board
PB1: U2.19 (PB1); also elsewhere on the board
PB2: U2.20 (PB2); also elsewhere on the board
PB3: U2.39 (PB3); also elsewhere on the board
PB4: U2.40 (PB4); also elsewhere on the board
PB6: U2.42 (PB6)
PB7: U2.43 (PB7)
PB8: U2.45 (PB8)
PB9: U2.46 (PB9)
PB10: U2.21 (PB10); also elsewhere on the board
PB11: U2.22 (PB11); also elsewhere on the board
PB12: U2.25 (PB12); also elsewhere on the board
PB13: U2.26 (PB13); also elsewhere on the board
PB14: U2.27 (PB14); also elsewhere on the board
PB15: U2.28 (PB15); also elsewhere on the board
SWCLK: J2.4 (SWCLK), U2.37 (PA14)
SWDIO: J2.2 (SWDIO), U2.34 (PA13)
VBUS: F1.2, J1.1, USB1.A4 (VBUS), USB1.A9 (VBUS), USB1.B4 (VBUS), USB1.B9 (VBUS)

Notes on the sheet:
Reset Bootloader
- -
ESD Protection Circuit
Voltage Converter
Serial Wire Debug
Press Press and Hold for 1s
Reset/Boot Circuit
USB Connector
UDB JST Connector

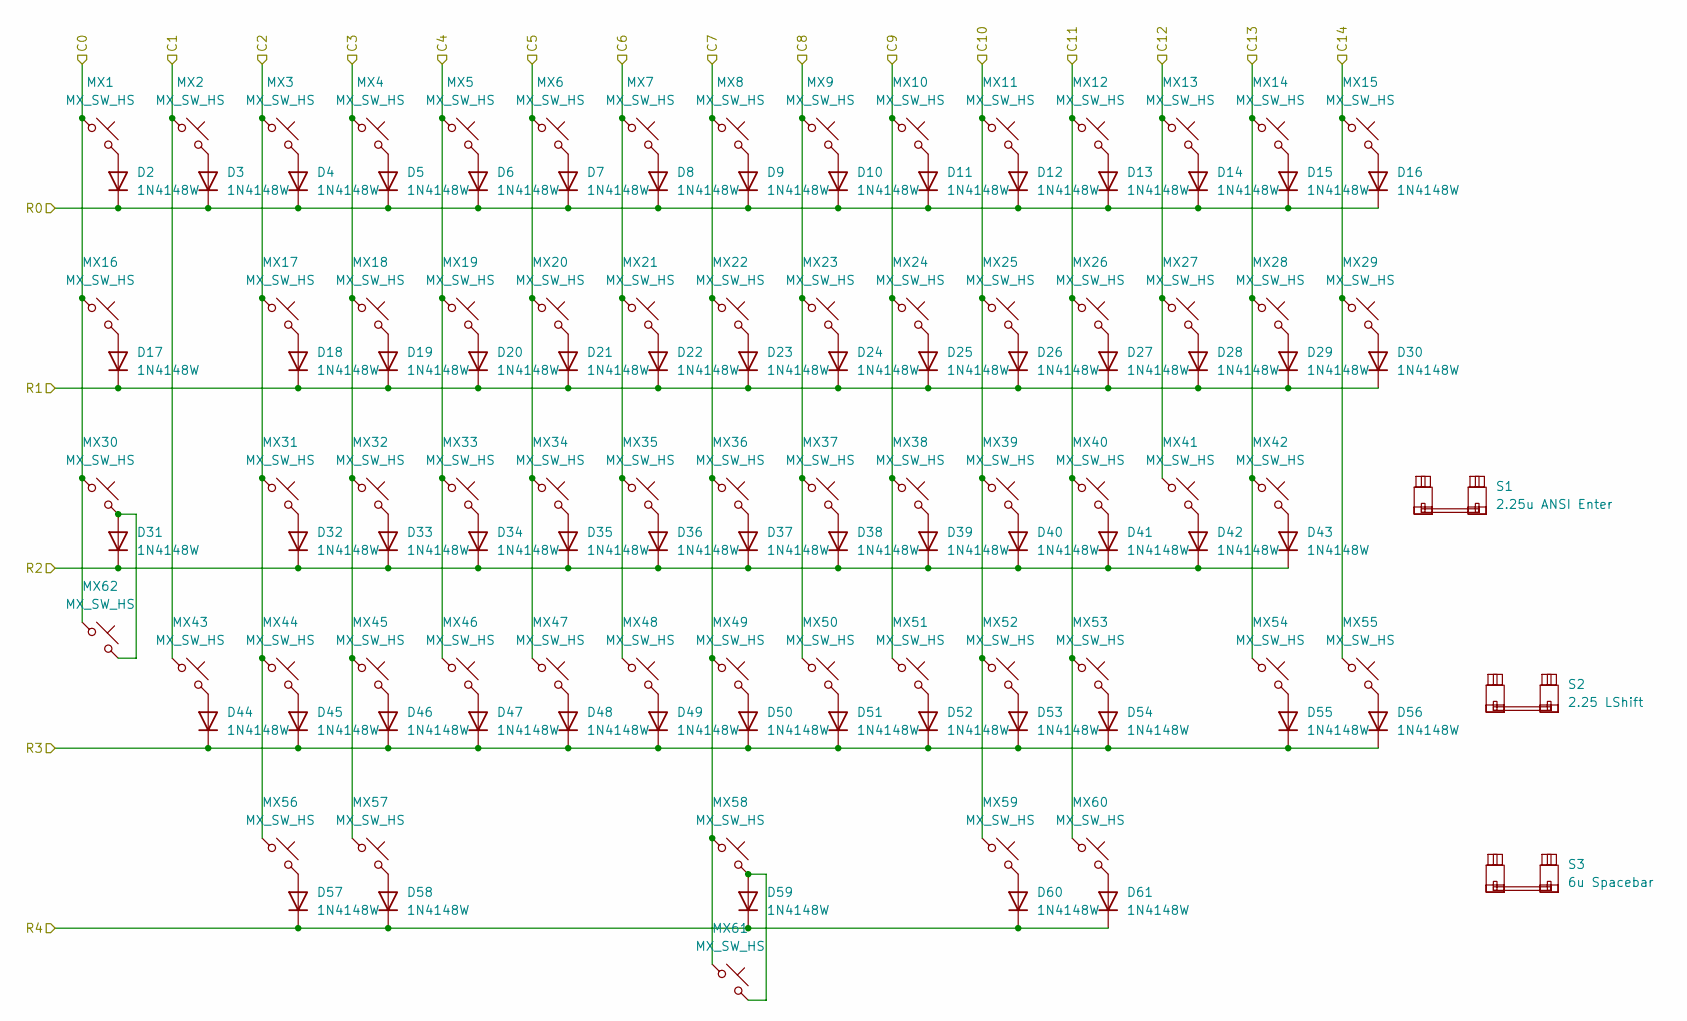
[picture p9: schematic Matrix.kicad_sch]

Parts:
D2, D3, D4, D5, D6, D7, D8, D9, D10, D11, D12, D13, D14, D15, D16, D17, D18, D19, D20, D21, D22, D23, D24, D25, D26, D27, D28, D29, D30, D31, D32, D33, D34, D35, D36, D37, D38, D39, D40, D41, D42, D43, D44, D45, D46, D47, D48, D49, D50, D51, D52, D53, D54, D55, D56, D57, D58, D59, D60, D61: 1N4148W; D_SOD-123
MX1, MX2, MX3, MX4, MX5, MX6, MX7, MX8, MX9, MX10, MX11, MX12, MX13, MX14, MX15, MX17, MX18, MX19, MX20, MX21, MX22, MX23, MX24, MX25, MX26, MX27, MX28, MX31, MX32, MX33, MX34, MX35, MX36, MX37, MX38, MX39, MX40, MX41, MX42, MX43, MX44, MX45, MX46, MX47, MX48, MX49, MX50, MX51, MX52, MX53, MX55, MX56, MX58, MX60, MX61: MX_SW_HS; SW_MX_HS_CPG151101S11_1u
MX16, MX29, MX57, MX59: MX_SW_HS; SW_MX_HS_CPG151101S11_1.5u
MX30, MX54: MX_SW_HS; SW_MX_HS_CPG151101S11_1.75u
MX62: MX_SW_HS; SW_MX_HS_CPG151101S11_1.75u_STP_1.25
S1: 2.25u ANSI Enter; STAB_MX_2.25u
S2: 2.25 LShift; STAB_MX_2.25u
S3: 6u Spacebar; STAB_MX_6u_New

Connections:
unnamed: D2.2 (A), MX1.2
unnamed: D3.2 (A), MX2.2
unnamed: D4.2 (A), MX3.2
unnamed: D5.2 (A), MX4.2
unnamed: D6.2 (A), MX5.2
unnamed: D7.2 (A), MX6.2
unnamed: D8.2 (A), MX7.2
unnamed: D9.2 (A), MX8.2
unnamed: D10.2 (A), MX9.2
unnamed: D11.2 (A), MX10.2
unnamed: D12.2 (A), MX11.2
unnamed: D13.2 (A), MX12.2
unnamed: D14.2 (A), MX13.2
unnamed: D15.2 (A), MX14.2
unnamed: D16.2 (A), MX15.2
unnamed: D17.2 (A), MX16.2
unnamed: D18.2 (A), MX17.2
unnamed: D19.2 (A), MX18.2
unnamed: D20.2 (A), MX19.2
unnamed: D21.2 (A), MX20.2
unnamed: D22.2 (A), MX21.2
unnamed: D23.2 (A), MX22.2
unnamed: D24.2 (A), MX23.2
unnamed: D25.2 (A), MX24.2
unnamed: D26.2 (A), MX25.2
unnamed: D27.2 (A), MX26.2
unnamed: D28.2 (A), MX27.2
unnamed: D29.2 (A), MX28.2
unnamed: D30.2 (A), MX29.2
unnamed: D31.2 (A), MX30.2, MX62.2
unnamed: D32.2 (A), MX31.2
unnamed: D33.2 (A), MX32.2
unnamed: D34.2 (A), MX33.2
unnamed: D35.2 (A), MX34.2
unnamed: D36.2 (A), MX35.2
unnamed: D37.2 (A), MX36.2
unnamed: D38.2 (A), MX37.2
unnamed: D39.2 (A), MX38.2
unnamed: D40.2 (A), MX39.2
unnamed: D41.2 (A), MX40.2
unnamed: D42.2 (A), MX41.2
unnamed: D43.2 (A), MX42.2
unnamed: D44.2 (A), MX43.2
unnamed: D45.2 (A), MX44.2
unnamed: D46.2 (A), MX45.2
unnamed: D47.2 (A), MX46.2
unnamed: D48.2 (A), MX47.2
unnamed: D49.2 (A), MX48.2
unnamed: D50.2 (A), MX49.2
unnamed: D51.2 (A), MX50.2
unnamed: D52.2 (A), MX51.2
unnamed: D53.2 (A), MX52.2
unnamed: D54.2 (A), MX53.2
unnamed: D55.2 (A), MX54.2
unnamed: D56.2 (A), MX55.2
unnamed: D57.2 (A), MX56.2
unnamed: D58.2 (A), MX57.2
unnamed: D59.2 (A), MX58.2, MX61.2
unnamed: D60.2 (A), MX59.2
unnamed: D61.2 (A), MX60.2
PA3: MX3.1, MX17.1, MX31.1, MX44.1, MX56.1; also elsewhere on the board
PA4: MX4.1, MX18.1, MX32.1, MX45.1, MX57.1; also elsewhere on the board
PA5: MX8.1, MX22.1, MX36.1, MX49.1, MX58.1, MX61.1; also elsewhere on the board
PA6: MX11.1, MX25.1, MX39.1, MX52.1, MX59.1; also elsewhere on the board
PA7: MX12.1, MX26.1, MX40.1, MX53.1, MX60.1; also elsewhere on the board
PA8: MX7.1, MX21.1, MX35.1, MX48.1; also elsewhere on the board
PA9: MX9.1, MX23.1, MX37.1, MX50.1; also elsewhere on the board
PA10: MX10.1, MX24.1, MX38.1, MX51.1; also elsewhere on the board
PA15: MX13.1, MX27.1, MX41.1; also elsewhere on the board
PB0: D57.1 (K), D58.1 (K), D59.1 (K), D60.1 (K), D61.1 (K); also elsewhere on the board
PB1: D44.1 (K), D45.1 (K), D46.1 (K), D47.1 (K), D48.1 (K), D49.1 (K), D50.1 (K), D51.1 (K), D52.1 (K), D53.1 (K), D54.1 (K), D55.1 (K), D56.1 (K); also elsewhere on the board
PB2: D31.1 (K), D32.1 (K), D33.1 (K), D34.1 (K), D35.1 (K), D36.1 (K), D37.1 (K), D38.1 (K), D39.1 (K), D40.1 (K), D41.1 (K), D42.1 (K), D43.1 (K); also elsewhere on the board
PB3: MX14.1, MX28.1, MX42.1, MX54.1; also elsewhere on the board
PB4: MX15.1, MX29.1, MX55.1; also elsewhere on the board
PB10: D17.1 (K), D18.1 (K), D19.1 (K), D20.1 (K), D21.1 (K), D22.1 (K), D23.1 (K), D24.1 (K), D25.1 (K), D26.1 (K), D27.1 (K), D28.1 (K), D29.1 (K), D30.1 (K); also elsewhere on the board
PB11: D2.1 (K), D3.1 (K), D4.1 (K), D5.1 (K), D6.1 (K), D7.1 (K), D8.1 (K), D9.1 (K), D10.1 (K), D11.1 (K), D12.1 (K), D13.1 (K), D14.1 (K), D15.1 (K), D16.1 (K); also elsewhere on the board
PB12: MX1.1, MX16.1, MX30.1, MX62.1; also elsewhere on the board
PB13: MX2.1, MX43.1; also elsewhere on the board
PB14: MX5.1, MX19.1, MX33.1, MX46.1; also elsewhere on the board
PB15: MX6.1, MX20.1, MX34.1, MX47.1; also elsewhere on the board

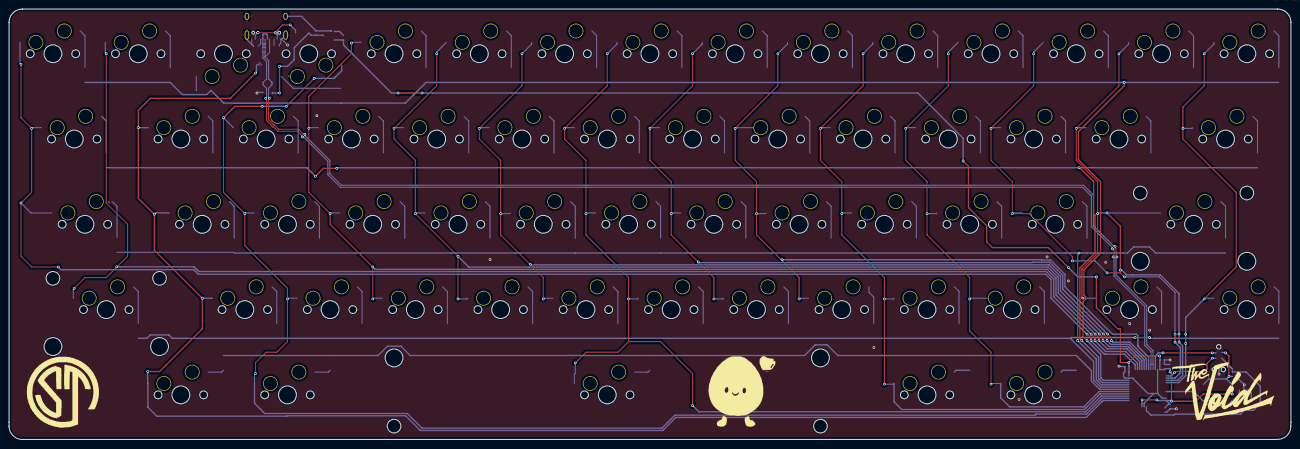
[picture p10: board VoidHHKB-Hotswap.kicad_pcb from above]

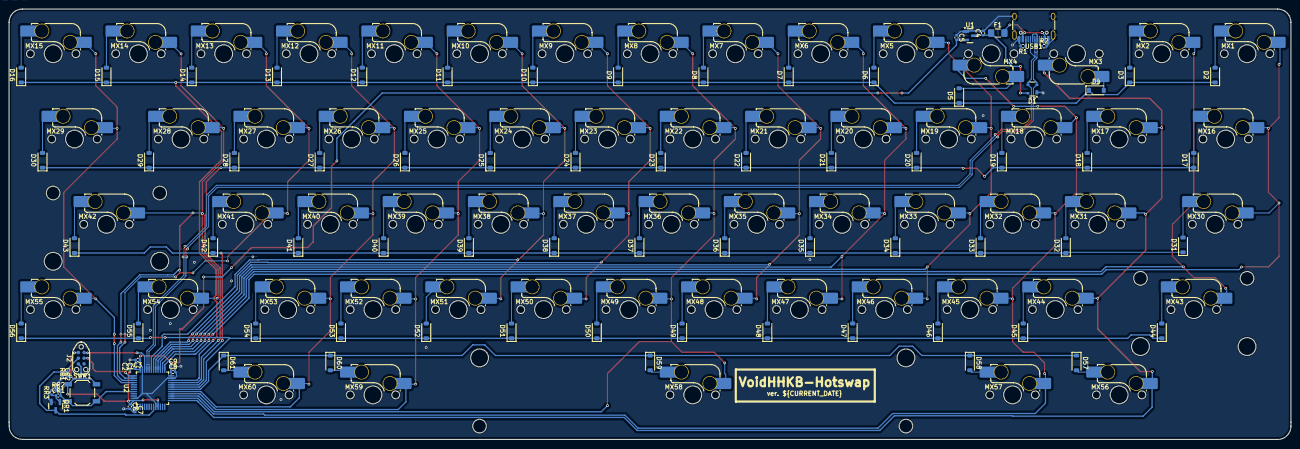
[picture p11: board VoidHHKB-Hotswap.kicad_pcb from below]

Board: 2 copper layers, 286.4 x 96.1 mm, 147 parts (144 on the bottom side), 93 nets.

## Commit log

2025-02-04 Initial Commit with all files for VoidHHKB-Hotswap
    [Matrix.kicad_sch, VoidHHKB-Hotswap.kicad_pcb, VoidHHKB-Hotswap.kicad_sch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]
2025-02-21 Removed switch sockets that can't be used due to plate limitations.
    [VoidHHKB-Hotswap.kicad_pcb, VoidHHKB-Hotswap.kicad_sch, bom.csv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]
2025-03-12 Add Solder PCB option (#6)
    * Added Solder PCB
    * Added solder pcb readme
    * Updated Solder PCB. Fix designators and add labels to silk screen.
    * Rearrange repo. Individual dir for each type
    * Updated firmware files
    * Updated solder readme
    [Matrix.kicad_sch, VoidHHKB-Hotswap.kicad_pcb, VoidHHKB-Hotswap.kicad_sch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]
